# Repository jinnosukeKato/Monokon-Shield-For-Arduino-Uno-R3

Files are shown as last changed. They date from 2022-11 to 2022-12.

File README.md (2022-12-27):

# Monokon-Shield for Arduino Uno R3

ものづくりコンテスト制御の対象基板、制作基盤と Arduino Uno R3 を接続するためのシールドです

[KiCad 6.0](https://www.kicad.org/) 用のデータです  
ガーバーファイルとドリルファイルを出力して、基板メーカ等に発注するなりしてください

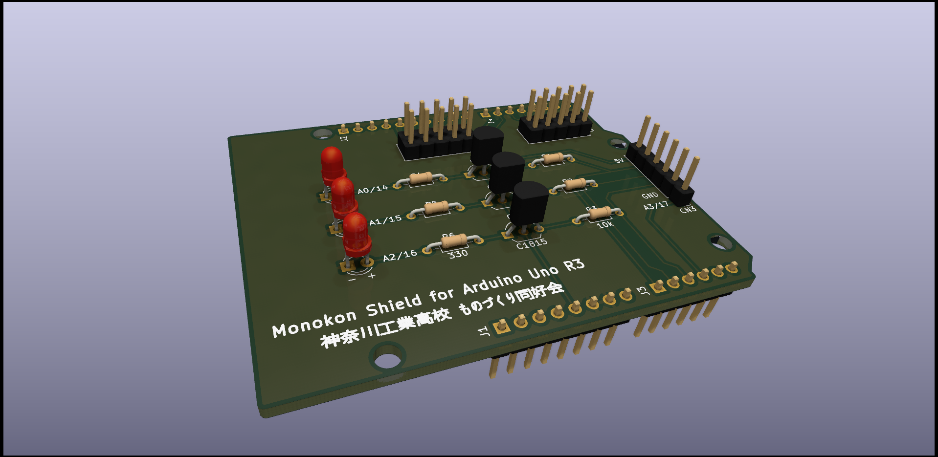
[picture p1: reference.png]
参考画像


## 特徴

- Arduino Uno R3 と同寸法
- デバッグ用LED搭載
- 一層基板

## 使いかた

この基盤をArduino Unoに差し込み、CN3に制作基盤(当日制作する基板)を接続し、CN1, CN2に制御対象基板を接続してください。

## 必要な部品

- [330Ω 抵抗器](https://akizukidenshi.com/catalog/g/gR-25331/) x3
- [10kΩ 抵抗器](https://akizukidenshi.com/catalog/g/gR-25103/) x3
- [C1815 トランジスタ](https://akizukidenshi.com/catalog/g/gI-06475/) x3
- [お好きな色のLED](https://akizukidenshi.com/catalog/g/gI-11333/) x3
- [10ピン ボックスヘッダ](https://akizukidenshi.com/catalog/g/gC-12664/) x2
- [2.54mm ピンヘッダ](https://akizukidenshi.com/catalog/g/gC-00167/)

## 組み立て上の注意点

- ランドが少し小さいです
- J1-4はピンが裏を向くように実装してください
- トランジスタの足は、ランドに適切に刺さるよう曲げてください
- CN1, CN2のフラットケーブルが交差してしまう配線になっています
- CN1, CN2が参考画像では10ピンヘッダになっていますが、ボックスヘッダを実装することをオススメします
- CN1, CN2にボックスヘッダを実装する場合は▼がLED側に来るように実装してください
- シルクに`神奈川工業高校 ものづくり同好会`と入ってます

## ピン対応表

| Arduinoのピン | 接続先 | メモ |
| --- | --- | --- |
| 0 | NC | - |
| 1 | NC | - |
| 2 | 7セグ左ON/OFF | - |
| 3 | 7セグ右ON/OFF | - |
| 4 | ブザー | tone()で鳴らしてください |
| 5 | クロック | DCモーター/ステッピングモーター使用時に入力必須 |
| 6 | 7セグ/ステッピング | 7セグのピンは一番上の横棒から時計回り |
| 7 | 7セグ/ステッピング | - |
| 8 | 7セグ/ステッピング | - |
| 9 | 7セグ/ステッピング | - |
| 10 | 7セグ/DCモーター | - |
| 11 | 7セグ/DCモーター | - |
| 12 | 7セグ | 中央横棒 |
| 13 | 7セグ | 小数点 |
| 14 | 製作基盤入力 | digitalRead用 |
| 15 | 製作基盤入力 | digitalRead用 |
| 16 | 製作基盤入力 | digitalRead用 |
| A0 | 製作基盤入力 | AnalogRead用 |
| A1 | 製作基盤入力 | AnalogRead用 |
| A2 | 製作基盤入力 | AnalogRead用 |

## Special Thanks

- K先輩(Arduino MEGA用の基盤データ提供、LEDの回路を参考にさせてもらいました)
- 神奈川工業高校ものづくり同好会

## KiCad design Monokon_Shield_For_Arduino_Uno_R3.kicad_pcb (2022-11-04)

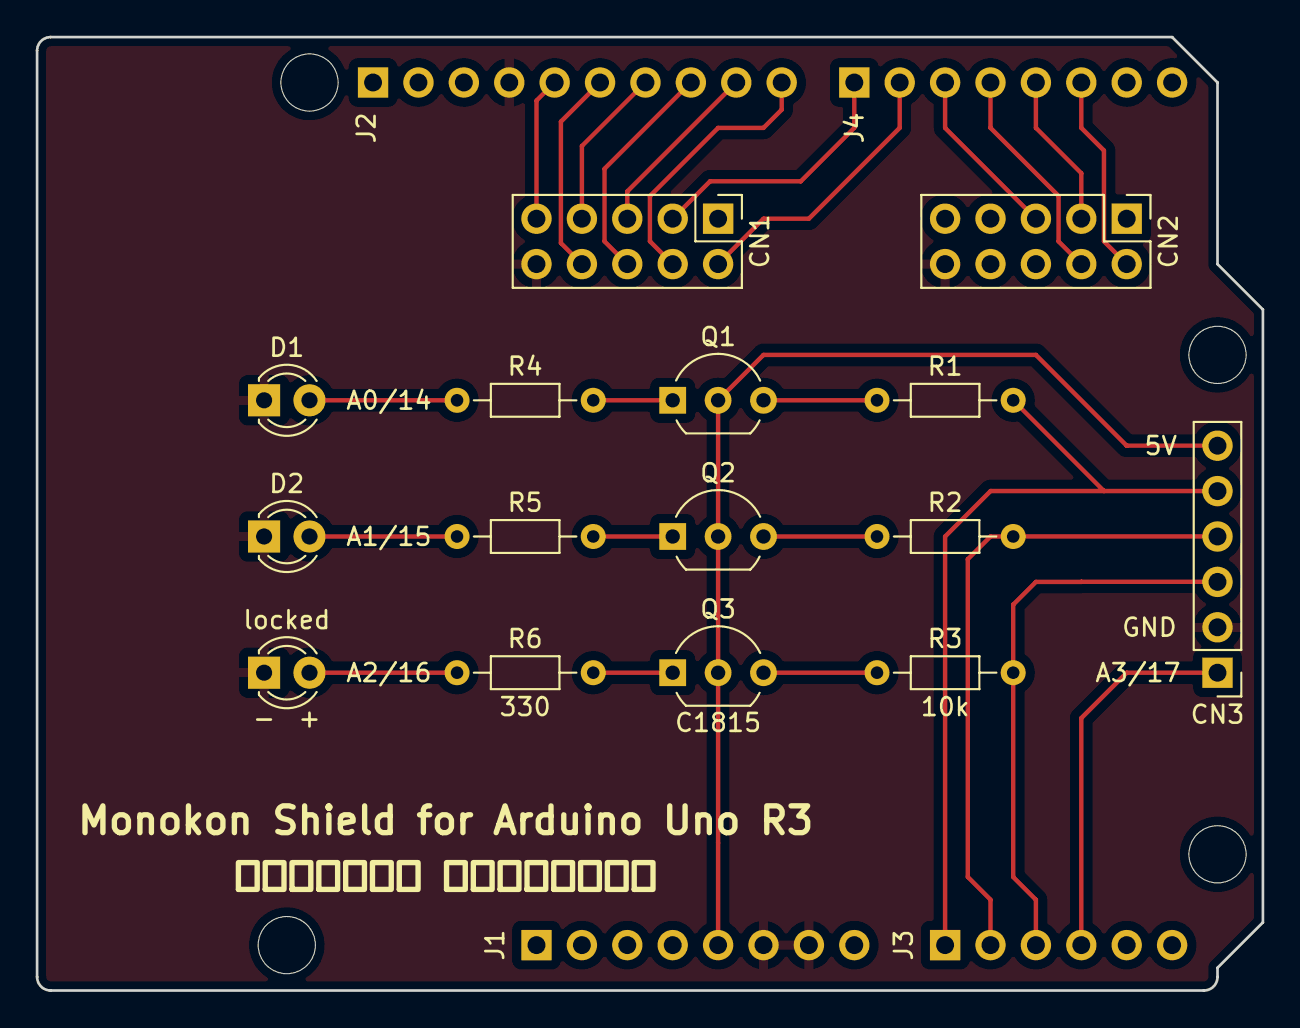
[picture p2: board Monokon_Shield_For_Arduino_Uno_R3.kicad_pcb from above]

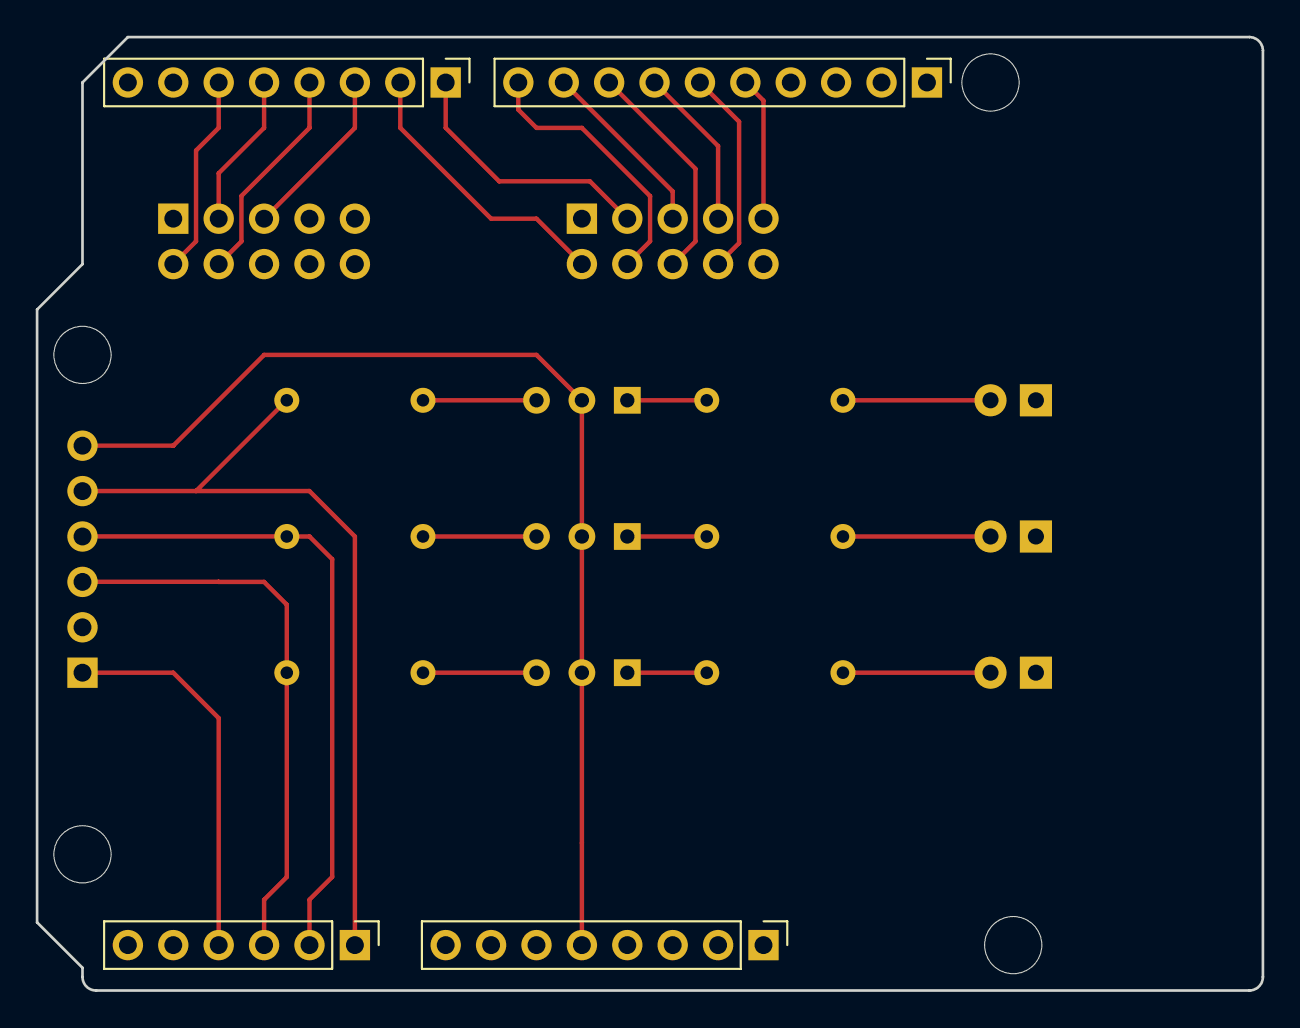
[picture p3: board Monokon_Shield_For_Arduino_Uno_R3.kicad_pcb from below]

Board: 2 copper layers, 68.6 x 53.3 mm, 23 parts (4 on the bottom side), 27 nets.

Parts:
CN1, CN2: 2x5 10-Pin Male Box Header; PinHeader_2x05_P2.54mm_Vertical
CN3: 6-Pin Headers; PinHeader_1x06_P2.54mm_Vertical
D1, D2: LED; LED_D3.0mm
J1: locked; PinHeader_1x08_P2.54mm_Vertical
J2: Digital/PWM; PinHeader_1x10_P2.54mm_Vertical
J3: Analog; PinHeader_1x06_P2.54mm_Vertical
J4: Digital/PWM; PinHeader_1x08_P2.54mm_Vertical
MH1, MH2, MH3, MH4: MountingHole_3.2mm
Q1, Q2, Q3: C1815; TO-92_Inline_Wide
R1, R2, R3: 10k; R_Axial_DIN0204_L3.6mm_D1.6mm_P7.62mm_Horizontal
R4, R5, R6: 330; R_Axial_DIN0204_L3.6mm_D1.6mm_P7.62mm_Horizontal
locked: LED; LED_D3.0mm

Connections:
2: CN2.2, J4.6
3: CN2.3, J4.5
4: CN2.4, J4.4
5: CN2.5, J4.3
6: CN1.2, J4.2
7: CN1.3, J4.1
8: CN1.4, J2.10
9: CN1.5, J2.9
10: CN1.6, J2.8
11: CN1.7, J2.7
12: CN1.8, J2.6
13: CN1.9, J2.5
+5V: CN3.6, J1.5, Q1.2 (C), Q2.2 (C), Q3.2 (C)
A0: CN3.5, J3.1, R1.1
A1: CN3.4, J3.2, R2.1
A2: CN3.3, J3.3, R3.1
A3: CN3.1, J3.4
GND: CN1.10, CN2.10, CN3.2, D1.1 (K), D2.1 (K), J1.6, J1.7, J2.4, locked.1 (K)
unnamed: D1.2 (A), R4.2
unnamed: D2.2 (A), R5.2
unnamed: R6.2, locked.2 (A)
unnamed: Q1.1 (E), R4.1
unnamed: Q1.3 (B), R1.2
unnamed: Q2.1 (E), R5.1
unnamed: Q2.3 (B), R2.2
unnamed: Q3.1 (E), R6.1
unnamed: Q3.3 (B), R3.2

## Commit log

2022-11-04 シルクの部品名を修正
    [Monokon_Shield_For_Arduino_Uno_R3.kicad_pcb]
2022-11-04 参考画像を追加
2022-11-04 ライセンスを追加
2022-11-04 readmeを追加
2022-11-08 ピンの対応表を追記
2022-12-04 組み立てて気づいたことを追記
2022-12-27 readme気になったから修正
